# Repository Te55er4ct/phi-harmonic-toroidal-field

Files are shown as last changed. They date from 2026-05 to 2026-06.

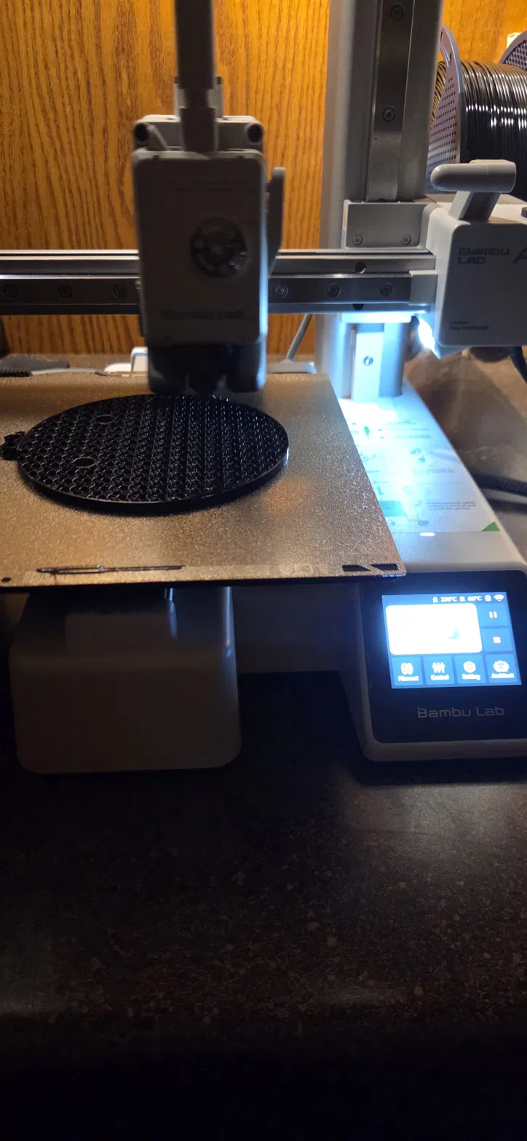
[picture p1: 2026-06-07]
sessions/2026-06-06_session1_v1/v1_first_print.png

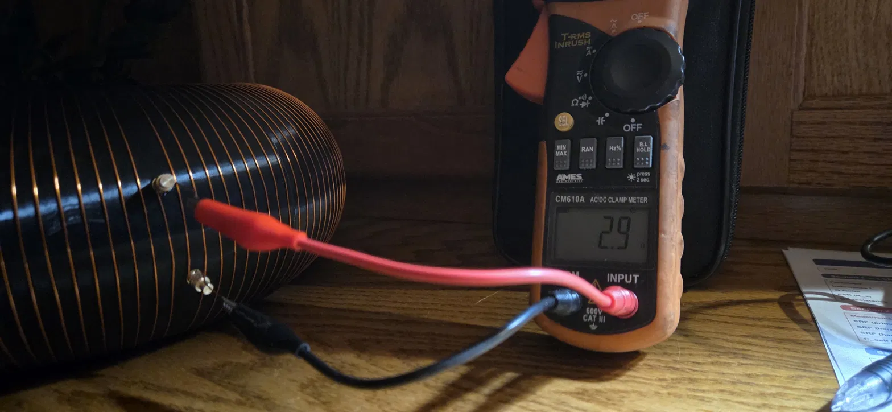
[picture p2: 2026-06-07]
sessions/2026-06-06_session1_v1/ohm_reading.png

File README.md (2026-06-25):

# Phi-Scaled Resonant Toroidal Research Platform
### *The Wierzbicki Phenomenon Omnivortex Device*
**Experimental Research · Ryan R. Wierzbicki · USA · 2026**

---

## Overview

This repository documents the design, fabrication, and experimental evaluation of a phi-proportioned toroidal field platform employing non-periodic winding geometry, Fibonacci-derived dimensional relationships, and multi-coil harmonic coupling at golden-angle offsets.

The platform investigates whether recursively phi-scaled toroidal structures and quasi-periodic winding distributions exhibit measurable differences in electromagnetic field organisation, resonance behaviour, harmonic distribution, and field coherence — compared to conventional toroidal architectures.

This project extends one specific, narrow, published result: Purnell et al.
(2018, *Physiological Reports*) reported that a phi-proportioned toroidal
electromagnetic array shifted human red blood cell morphology toward
golden-ratio proportions in a small (n=20), single-device, non-replicated
pilot study. That study used DC excitation through a conductive saline bath
and had no non-phi control geometry, so it cannot distinguish whether phi
geometry specifically — versus toroidal topology generally, the DC field, or
the saline coupling — is the active variable. This platform's three-version
comparative design (V1/V2/V3) exists to isolate that variable using an AC,
air-core implementation. See `docs/literature_review.md` for the full
evidentiary basis and explicit scope limits.

Cymatics (Jenny, 1967–74) motivates the node-frequency predictions tested in
Phase 2 — this is a citable, real body of acoustic-physics work, not a
biological claim. No claims of overunity performance, violation of
established physical law, or therapeutic/disease-treatment efficacy are
made. The purpose of this platform is experimental investigation of
measurable electromagnetic phenomena — inductance, Q, resonant frequency,
field distribution — produced by phi-harmonic geometry.

---

## Research Objectives

The platform is designed to investigate the following specific questions:

1. Do phi-proportioned toroidal geometries (R/r = φ) produce measurably different field distributions compared to non-phi toroidal geometries with identical winding configurations?

2. Do quasi-periodic winding offsets at the golden angle (137.5°) produce measurably different standing-wave node distributions compared to evenly periodic winding arrangements?

3. Do three mutually coupled windings in phi-harmonic phase relationships produce emergent field phenomena not predicted by analysis of each winding in isolation?

4. Does the combination of opposing primary and counter windings produce any measurable difference in Faraday-cage transmission compared to a single-winding control? (Framed as an electrical engineering question; see `docs/literature_review.md` §III for why this is not framed in terms of scalar-wave theory.)

5. Are Fibonacci node positions — predicted by the phi-spiral winding geometry — measurably associated with field concentration or standing-wave formation?

6. Do phi-harmonic driving frequencies (f(n) = 111 × φ^(n/3) Hz) produce resonant behaviour distinct from non-harmonic driving frequencies in this geometry?

---

## Theoretical Foundation

### The Motivating Result

Purnell et al. (2018, *Physiological Reports*) reported that a
phi-proportioned toroidal electromagnetic array shifted human red blood
cell morphology toward golden-ratio proportions in a small (n=20),
single-device, non-replicated pilot study using DC excitation through a
saline bath. The study had no non-phi control geometry, so it cannot
isolate whether phi geometry, toroidal topology generally, the DC field,
or the saline coupling produced the effect. This platform's V1/V2/V3
comparative design exists to isolate that variable with an AC, air-core
implementation. Full evidentiary basis and scope limits: `docs/literature_review.md`.

### Faraday-Cage Transmission Test

The V3 winding architecture (opposing primary/counter windings, 120° phase
offset) will be compared against V1/V2 single-winding controls for any
measurable difference in transmission through a grounded Faraday enclosure.
This is framed as an electrical engineering measurement, not as a test of
scalar-wave theory — see `docs/literature_review.md` §III for why that
framework is explicitly not part of this project's evidentiary basis. Any
unexpected result will be investigated via conventional EM coupling
mechanisms first.

### Cymatic Field Organisation

Jenny (1967–1974) demonstrated that specific driving frequencies produce reproducible geometric standing-wave patterns in physical media. The phi-harmonic node frequency series (111 × φ^(n/3) Hz) is predicted to produce distinct cymatic patterns corresponding to Fibonacci symmetry orders (3-fold, 5-fold, 8-fold, 13-fold) at successive node positions around the torus equator. This prediction is directly testable.

### Phi Geometry as Organisational Principle

The golden ratio φ = (1+√5)/2 = 1.6180... appears as a growth ratio throughout biological systems — phyllotaxis, vascular branching, neural architecture — because it maximises spatial coverage without self-overlap. The hypothesis under investigation is that a toroidal field structure proportioned to φ is geometrically congruent with biological field structures in a way that conventional integer-ratio geometries are not.

---

## Experimental Design

### Three-Version Comparative Framework

| Version | Label | Geometry | Winding | Variable Under Test |
|---|---|---|---|---|
| V1 | Control | Standard (R=80mm, r=45mm) | Poloidal standard | Baseline |
| V2 | Phi-Shell | Phi-proportioned (R=89mm, r=55mm) | Poloidal standard | Phi geometry alone |
| V3 | Omnivortex | Phi-proportioned (R=89mm, r=55mm) | Three phi-spiral windings | Phi geometry + phi winding |

This design enables isolation of the geometric effect (V1 vs V2), the winding effect (V2 vs V3), and the combined effect (V1 vs V3).

### Device Specifications

| Parameter | V1 Control | V2 Phi-Shell | V3 Omnivortex |
|---|---|---|---|
| Major Radius R | 80 mm | 89 mm (F11) | 89 mm (F11) |
| Minor Radius r | 45 mm | 55 mm (F10) | 55 mm (F10) |
| R / r | 1.778 | 1.618 (φ) | 1.618 (φ) |
| Outer Diameter | 250 mm | 288 mm | 288 mm |
| Winding type | Poloidal | Poloidal | Phi-spiral |
| Winding count | 1 | 1 | 3 |
| Turn count | 50 | 50 | 5 per winding |

---

## V3 Omnivortex Winding Architecture

| Winding | Colour | Gauge | Direction | Phase Offset |
|---|---|---|---|---|
| Primary | Red enamel | 18 AWG | Clockwise | 0° |
| Counter | Blue enamel | 18 AWG | Counter-clockwise | 120° |
| Harmonic | Green enamel | 20 AWG | Phi-rate advance | 137.5° (golden angle) |

Each winding closes at its own node contact — creating three closed toroidal inductors within the same phi-proportioned geometry. The harmonic winding advances at the golden angle per major turn (minor turns = major turns × φ = 8.09).

---

## Fibonacci Node Geometry

| Node | Angle | Predicted Frequency | Predicted Cymatic Form |
|---|---|---|---|
| 1 | 0.0° | 111.00 Hz | 3-fold symmetry |
| 2 | 137.5° | 130.31 Hz | 5-fold symmetry |
| 3 | 275.0° | 152.98 Hz | 6-fold symmetry |
| 4 | 52.5° | 179.60 Hz | 5-fold + ring |
| 5 | 190.0° | 210.85 Hz | 8-fold symmetry |
| 6 | 327.5° | 247.53 Hz | 8-fold + ring |
| 7 | 105.0° | 290.60 Hz | 13-fold symmetry |
| 8 | 242.6° | 341.16 Hz | Complex composite |

Node frequency series: **f(n) = 111 × φ^(n/3) Hz**

---

## Mathematical Framework

**Toroidal parametric surface:**

    P(t) = ( (R + r·cos(φ·t))·cos(t),  (R + r·cos(φ·t))·sin(t),  r·sin(φ·t) )

**Node frequency series:**

    f(n) = 111 × φ^(n/3)  Hz,   n = 0, 1, 2, ... 7

**Golden angle:**

    GA = 360 / φ² = 137.5077...°

**Standing-wave membrane model:**

    u(r, θ, t) = sin(m·π·r/R) · cos(n·θ) · cos(ω·t)

**Fibonacci dimensional relationships:**

    R = 89 mm = F(11),   r = 55 mm = F(10),   R/r = 1.6182 ≈ φ

---

## Measurement Protocol

### Phase 1 — Electromagnetic Characterisation
Instruments: LCR meter, oscilloscope, function generator, NanoVNA

- Inductance and Q factor comparison across V1, V2, V3
- Resonance frequency mapping and harmonic spectrum analysis
- Impedance sweep 1 Hz – 10 MHz
- Phase relationships between V3 windings

### Phase 2 — Field Distribution Mapping
Instruments: Gaussmeter, Arduino sweep driver

- Near-field magnetic flux mapping at predicted node positions
- Standing-wave node detection using particle medium
- Cymatic pattern documentation at each node frequency

### Phase 3 — Faraday-Cage Transmission Test
Instruments: Paired coil sets, oscilloscope, Faraday cage

- Faraday cage transmission test: V1 vs V2 vs V3
- Phase velocity measurement
- Any anomalous result investigated via conventional EM coupling mechanisms
  before any other interpretation

### Phase 4 — Biological Response Investigation

*Phase 4 investigations will be conducted within applicable regulatory
frameworks (IRB-equivalent oversight required for any biological subject)
and will not involve therapeutic claims. This phase is a long-horizon,
not-yet-scoped extension and is not a current commitment.*

- Replication attempt of Purnell (2018) RBC morphology measurement,
  parametrized across V1/V2/V3 to test whether phi geometry specifically
  is the active variable

---

## Driver Circuit

| Parameter | Value |
|---|---|
| Driver | 2 × L298N H-bridge + Arduino Nano |
| Supply voltage | 12V DC regulated |
| Series resistance | 1.5Ω 10W per winding |
| Peak current | ~7A per winding |
| Frequency range | 1 Hz – 100 kHz |
| Drive modes | In-phase / Anti-phase / Phase-offset / Sequential |

---

## Fabrication

All structural components are 3D-printed in PETG from parametrically generated STL files produced by `TorusGenerator.java` — a pure-Java parametric STL generator operating directly from mathematical definitions.

| Parameter | Value |
|---|---|
| Material | PETG |
| Segments | 8 per torus (45° arc each) |
| Layer height | 0.20 mm |
| Infill | Honeycomb 30% |
| Wall perimeters | 4 |
| Supports | None required |

---

## Historical Precedents

| Researcher | Year | Contribution |
|---|---|---|
| Nikola Tesla | 1898 | High-frequency electromagnetic therapeutic effects |
| Georges Lakhovsky | 1925 | Cellular LC oscillation theory; MWO clinical trials |
| Hans Jenny | 1967–74 | Cymatic standing-wave geometry at discrete frequencies |
| Herbert Fröhlich | 1968 | Quantum coherence in biological systems |
| Konstantin Meyl | 2001 | Scalar longitudinal wave theory and experimental replication |
| Thomas Valone | 2003 | Bioelectromagnetic healing: historical record and biophysical rationale |

---

## Current Status

| Date | Milestone |
|---|---|
| May 2026 | Theoretical framework complete |
| May 2026 | Parametric geometry and Java STL generator complete |
| May 2026 | Driver circuit specification complete |
| May 2026 | Repository established — public priority record |
| May 2026 | Documentation complete. Awaiting first print. |
| May 23, 2026 | First segment printed — V1 control |
| May 23, 2026 | OpenSCAD geometry validated — slits, pegs, sockets |
| May 23, 2026 | Bambu Lab A1 Mini operational |
| May 24, 2026 | Toroidal segment peg/socket alignment validated procedurally |
| May 24, 2026 | 45° segmented toroid architecture finalized for V1 testing 
| June 6, 2026 | **Phase 1 attempted — V1 only.** Measured L=0.47 mH, Q~161 @500kHz (dropping to ~14 near SRF), SRF≈1.000 MHz, C_self≈54 pF, DC resistance 2.9Ω, anti-resonance at 12.005 MHz. Wheeler-formula comparison corrected (predicted 0.323 mH; measured is ~45% higher, likely turn-to-turn proximity/mutual coupling not captured by the idealized formula). V2/V3 not yet built — Phase 1's full V1/V2/V3 comparison is not yet possible. |
| TBD | Phase 1 completion — V2/V3 build and measurement |
| TBD | Phase 2 field distribution mapping |
| TBD | Phase 3 Faraday-cage transmission test |
| TBD | Phase 4 biological response investigation |

---

## Research Position

This project investigates unconventional resonant geometries and winding architectures within experimental electromagnetic research. All measurements will employ appropriate instruments, documented procedures, and comparative baselines.

**This project does not claim:**
- Perpetual motion or overunity performance
- Violation of conservation of energy or Maxwell's equations
- Confirmed anomalous physics prior to experimental verification
- Therapeutic efficacy in the absence of controlled experimental data

**This project does claim:**
- Original parametric design of a phi-proportioned three-winding toroidal field platform
- Rigorous three-version experimental design for variable isolation
- Public priority record established May 2026
- Open research for collaborative independent verification

---

## License

Open research publication for collaborative experimentation and independent verification.  
All original theory, design, and documentation © R. Wierzbicki, 2026.  
Attribution required for derivative work and published results.

---

*"The convergence of φ, the Fibonacci sequence, toroidal geometry, Tesla's 3·6·9,  
and a century of bioelectromagnetic research is not accidental.  
They are different descriptions of the same underlying structure —  
the way energy organises itself when given the freedom to do so."*

— R. Wierzbicki, 2026

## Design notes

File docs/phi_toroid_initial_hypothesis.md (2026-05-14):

# Quasi-Periodic Toroidal Resonance Structures
## Initial Engineering Hypothesis & Research Framework

---

# Abstract

This project investigates whether quasi-periodic toroidal winding geometries exhibit measurable electromagnetic behaviors distinct from conventional periodic toroidal winding architectures.

The research focuses specifically on:

- distributed parasitic capacitance,
- resonance bandwidth characteristics,
- harmonic distribution,
- inductive coupling behavior,
- field topology,
- and electromagnetic interference behavior.

The central experimental concept is a toroidal multi-winding structure utilizing irrational angular traversal relationships derived from golden-angle distributions and Fibonacci-scaled winding ratios.

Unlike conventional evenly periodic toroidal windings, the proposed architecture intentionally prevents exact spatial repetition of winding overlap across the toroidal surface.

The project does not begin with assumptions regarding:

- overunity,
- vacuum energy extraction,
- anomalous power generation,
- or nonphysical energy systems.

Instead, the project investigates whether non-periodic resonant geometries may produce useful and measurable electromagnetic behaviors comparable to other known aperiodic systems in:

- metamaterials,
- quasi-crystal structures,
- topological photonics,
- fractal antennas,
- and magnetic confinement topology.

---

# 1. Research Motivation

Modern electromagnetic systems are increasingly limited by:

- parasitic capacitance,
- harmonic congestion,
- EMI leakage,
- resonance instability,
- distributed coupling artifacts,
- and high-frequency interference.

Conventional toroidal windings are typically periodic structures with uniformly repeating turn spacing.

This creates predictable distributed capacitive networks and repeated field overlap regions.

The present research explores whether quasi-periodic winding distributions may:

- distribute harmonic interactions more uniformly,
- reduce localized field concentration,
- broaden resonance response,
- suppress sharp parasitic resonant spikes,
- or alter coupling topology.

The project draws conceptual inspiration from:

- Nikola Tesla's emphasis on resonance and harmonic systems,
- Georges Lakhovsky's broadband oscillatory concepts,
- toroidal confinement geometry in stellarator research,
- quasi-periodic mathematical systems,
- and modern topological electromagnetic research.

However, all project development is grounded in experimentally measurable electromagnetic behavior.

---

# 2. Foundational Hypothesis

## Primary Hypothesis

Quasi-periodic toroidal winding distributions alter distributed parasitic capacitance and harmonic resonance behavior compared to conventional periodic toroidal winding architectures.

---

## Secondary Hypotheses

### H1 — Harmonic Distribution

Quasi-periodic winding traversal produces broader and less sharply localized harmonic resonance structures than periodic windings.

---

### H2 — Distributed Capacitance

Irrational angular winding distributions reduce repeated parallel overlap regions and therefore alter effective distributed capacitance.

---

### H3 — Resonance Bandwidth

Non-periodic winding structures broaden impedance response curves and reduce narrow self-resonant spikes.

---

### H4 — Coupling Topology

Counter-wound quasi-periodic structures produce measurable differences in inductive coupling behavior under dynamic load conditions.

---

### H5 — Field Distribution

Quasi-periodic toroidal geometries produce distinguishable near-field spatial distributions relative to periodic toroidal controls.

---

# 3. Mathematical Framework

## Golden Angle Distribution

The winding traversal uses the golden angle:

φ = (1 + √5) / 2 ≈ 1.6180339887

Golden Angle:

θg = 2π / φ² ≈ 137.507764°

The golden angle is significant because irrational angular progression prevents exact spatial repetition.

This creates quasi-periodic surface coverage similar to:

- phyllotaxis distributions,
- irrational rotational systems,
- low discrepancy sequences,
- and quasi-crystal packing structures.

---

## Toroidal Traversal

The winding path is parameterized over a toroidal manifold.

Poloidal progression:

θ(t) = ±2πNt

Toroidal progression:

φ(t) = Nθg t + φ₀

Where:

- N = winding turns,
- θg = golden angle,
- φ₀ = phase offset,
- t ∈ [0,1]

This creates a quasi-periodic winding lattice over the toroidal surface.

---

## Fibonacci Scaling

Fibonacci relationships are used as proportional design constraints rather than as claims of intrinsic physical significance.

Example winding relationships:

- Primary: 144 turns
- Counter: 89 turns
- Harmonic: 55 turns

These relationships maintain recursive scaling and irrational ratio relationships between winding systems.

---

# 4. Experimental Architecture

## Geometry

Toroidal geometry:

- Major radius: R
- Minor radius: r
- Ratio: R/r ≈ φ

The device uses:

- primary winding layer,
- counter-wound layer,
- harmonic winding layer,
- axial reference structure,
- and distributed tap-node regions.

---

## Winding Structure

### Primary Layer

- clockwise traversal
- quasi-periodic toroidal progression
- primary excitation winding

### Counter Layer

- counter-clockwise traversal
- offset phase relationship
- inductive interaction layer

### Harmonic Layer

- reduced turn count
- secondary coupling topology
- distributed harmonic interaction

---

## Materials

Initial prototypes are intended for:

- low-cost fabrication,
- rapid iteration,
- and comparative testing.

Initial materials:

- PETG or PLA toroidal forms,
- enamel copper magnet wire,
- optional ferrite inserts,
- non-ferromagnetic fasteners.

---

# 5. Experimental Methodology

## Control Structure

A conventional periodic toroidal winding shall be constructed as a control.

The control and experimental structures shall maintain:

- identical dimensions,
- identical wire gauge,
- identical turn count,
- identical core material,
- and identical testing conditions.

Only winding topology shall differ.

---

## Measured Parameters

Initial measurements include:

### Electrical

- inductance,
- impedance,
- self-resonant frequency,
- Q factor,
- distributed capacitance,
- harmonic spectra,
- coupling efficiency,
- and thermal behavior.

### Field Measurements

- near-field magnetic mapping,
- EMI leakage,
- resonance spatial distribution,
- and coupling topology.

### Instrumentation

Potential instrumentation includes:

- oscilloscope,
- vector network analyzer,
- SDR spectral analysis,
- impedance analyzer,
- current probes,
- and field probes.

---

# 6. Related Scientific Domains

The project intersects conceptually with several established research territories.

---

## 6.1 Stellarator and Magnetic Confinement Topology

Fusion confinement systems such as stellarators utilize nontrivial toroidal magnetic geometries to maintain stable field structures.

In such systems:

- irrational rotational transforms,
- non-periodic field topology,
- and ergodic field traversal

strongly influence confinement behavior.

The present project does not claim equivalence with plasma confinement systems.

However, these systems demonstrate that toroidal topology and quasi-periodic field organization can significantly affect field behavior.

---

## 6.2 Metamaterials and Topological Electromagnetics

Modern metamaterial and topological photonics research demonstrates that:

- geometry,
- boundary conditions,
- and non-periodic structures

can alter wave propagation behavior.

Relevant adjacent concepts include:

- toroidal dipoles,
- anapole modes,
- structured wavefronts,
- and topological field organization.

---

## 6.3 Aperiodic RF Structures

Nonuniform resonant structures are already used in:

- fractal antennas,
- log-periodic antennas,
- distributed RF structures,
- and broadband impedance systems.

These systems demonstrate that non-periodic geometry can measurably affect:

- resonance,
- bandwidth,
- and harmonic behavior.

---

# 7. Current Project Position

At the present stage, the project should be considered:

- exploratory,
- experimental,
- geometry-driven,
- and measurement-focused.

No claims are currently made regarding:

- excess energy generation,
- vacuum energy extraction,
- scalar energy,
- or violations of established electromagnetic theory.

The project instead seeks to determine whether quasi-periodic toroidal winding structures produce measurable and potentially useful electromagnetic characteristics.

---

# 8. Initial Research Roadmap

## Prototype 0 — Control Toroid

Conventional periodic winding.

Purpose:

- baseline resonance behavior,
- baseline parasitic response,
- baseline harmonic spectra.

---

## Prototype 1 — Golden-Angle Winding

Single quasi-periodic winding.

Purpose:

- compare resonance response,
- compare harmonic distribution,
- compare self-resonance.

---

## Prototype 2 — Counter-Wound Structure

Add secondary counter-wound layer.

Purpose:

- investigate coupling behavior,
- phase interaction,
- and harmonic redistribution.

---

## Prototype 3 — Multi-Layer Harmonic Structure

Introduce harmonic scaling layer.

Purpose:

- broadband response analysis,
- distributed coupling studies,
- and modal interaction analysis.

---

# 9. Conclusion

The project has evolved from conceptual resonance exploration into a structured investigation of quasi-periodic electromagnetic geometry.

The central premise is not that geometry creates energy.

Rather:

The project investigates whether non-periodic toroidal winding architectures organize electromagnetic interactions differently than conventional periodic structures.

This question is:

- measurable,
- experimentally approachable,
- and grounded in adjacent domains of modern electromagnetic research.

The immediate objective is therefore:

To build repeatable, instrumented prototypes capable of generating comparative data between periodic and quasi-periodic toroidal winding systems.

Only measured and repeatable behavior will determine future theoretical development.

---

The project has evolved from conceptual resonance exploration into a structured investigation of quasi-periodic electromagnetic geometry.

The central premise is not that geometry creates energy.

Rather:

The project investigates whether non-periodic toroidal winding architectures organize electromagnetic interactions differently than conventional periodic structures.

This question is:

- measurable,
- experimentally approachable,
- and grounded in adjacent domains of modern electromagnetic research.

The immediate objective is therefore:

To build repeatable, instrumented prototypes capable of generating comparative data between periodic and quasi-periodic toroidal winding systems.

Only measured and repeatable behavior will determine future theoretical development.

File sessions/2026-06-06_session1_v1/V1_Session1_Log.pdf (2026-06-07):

## Omnivortex V1 — Phase 1 Session 1 Measurement Log

R=89mm r=55mm · 123T · 22 AWG · github.com/Te55er4ct/phi-harmonic-toroidal-field

Date: | 06/06/2026 | Time: 15:03-16:44 CDT | Temp: 84°F outdoor | Humidity: | 38% | Location: | Outdoors / wooden sawhorse
Section 1 — LCR Meter (Proster BM4070) | Fixed freq ~1kHz
Parameter | ~1kHz | 10kHz | 100kHz | Units | Notes
Inductance L | 0.47 | — | — | mH | Confirmed indoors & outdoors
Q factor | ~1.0 | — | — | — | Calc: wL/R; NanoVNA: 161@500k, 14@SRF
ESR (R_s) | — | — | — | ohm | Not displayed on BM4070
DC resistance | 2.9 | — | — | ohm | Ames CM610A clamp meter
Section 2 — NanoVNA-H Self-Resonant Frequency | fw v1.2.44 / Saver 0.7.3
Measurement | Value | Units | Notes
SRF primary peak | ~1.000 | MHz | Phase zero crossing 1.000-1.00040 MHz
SRF harmonic 2 | — | MHz | Not yet measured
SRF harmonic 3 | — | MHz | Not yet measured
C_self calculated | ~54 | pF | C=1/(4pi^2 x f^2 x L)

### Section 3 — Impedance Sweep Key Points (500kHz - 30MHz)

Feature | Freq (MHz) | |Z| (ohm) | Phase (deg) | Notes
Inductive region low end | 0.500 | ~1880 | +3.04 | Series L ~600uH, Q=161
SRF primary | ~1.000 | ~10500 | ~0 | Phase zero crossing confirmed
Q at SRF | ~1.000 | ~10500 | ~0 | Q = ~14 near SRF
Capacitive region start | >1.001 | — | neg | Series L goes negative
VSWR minimum (wide) | 12.005 | 141 | -20.53 | Min VSWR 6.452
Anti-resonance | 12.005 | 141 | -20.53 | Series L = -2.06uH
Upper limit | 30.000 | — | — | No further features this session

### Section 4 — Instrument & File Log

Cal file: | | V1_500k_30M (OSL via calibration assistant)
.s1p file: | | V1_SRF_1M.s1p
Screenshots: | nanovna_2026-06-06_16-12-32 thru 16-44-31 (8 captures)
NanoVNA fw: | NanoVNA-H v1.2.44
Instruments: | Proster BM4070 LCR | Ames CM610A clamp | NanoVNA-H

Observations / anomalies / notes
L=0.47mH confirmed identical indoors and outdoors — no EMI effect from indoor environment on LCR reading. SRF ~1.000MHz by phase zero crossing. Capacitive above, inductive below. C_self ~54pF calculated. NanoVNA SOL cal failed at 100k and 500k start frequencies. Resolved via calibration assistant at 500k. Connection: bare coil wire wrapped on SMA connector. SMA-to-alligator pigtails needed for Session 2.
DC resistance 2.9 ohm (spec 3.0 ohm). WiFi active on laptop — no artifacts visible in sweep range.
Operator: | Wierzbicki | Session #: | 1 | Git commit hash: | (fill after push)
Wierzbicki Phenomenon Omnivortex Device | V1 Phase 1 Session 1 | 06 June 2026 | github.com/Te55er4ct/phi-harmonic-toroidal-field

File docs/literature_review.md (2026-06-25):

# Literature Review & Research Precedents
## Phi-Harmonic Toroidal Field Research

---

## Introduction

This project tests a narrow, falsifiable engineering question: does
phi-proportioned toroidal coil geometry and golden-angle (137.5°) winding
distribution produce measurably different electrical and field
characteristics compared to a conventional toroid wound with the same wire
gauge, turn count, and core dimensions?

This document surveys the published work directly relevant to that question.
It deliberately excludes sources whose claims are not accepted by mainstream
physics or medicine, even where those sources historically inspired interest
in resonance-based or toroidal devices. Citing discredited or non-replicated
work as supporting evidence would misrepresent the actual evidentiary basis
for this project and invites — correctly — the "quack device" framing this
project should avoid. The honest position is: this is original instrumentation
work motivated by one narrow, real, non-replicated prior result, not a
synthesis of an established field.

---

## I. THE PRIOR RESULT THIS PROJECT EXTENDS

### Purnell, M.C., Butawan, M.B.A., Ramsey, R.D. — "Bio-field array: a
dielectrophoretic electromagnetic toroidal excitation to restore and
maintain the golden ratio in human erythrocytes" (2018)
*Physiological Reports, Vol. 6, Issue 12*
*US Patent 2017/0232253; PCT/US18/26932*

**What it is:** An IRB-approved human pilot study (n=20) using a toroidal
electromagnetic array with phi-proportioned geometry, DC-excited (2.5–3A)
through conductive rings in a hypotonic saline foot bath. Measured red
blood cell morphology and select serum chemistry before/after six
35-minute sessions over two weeks.

**Reported results:** RBC morphology shifted toward golden-ratio
proportions following treatment; reduced rouleaux (RBC stacking)
formation; decreased serum CO2 (p=0.017).

**What this does and does not establish:**
- It is the only published human trial of a phi-proportioned toroidal EM
  device that this review identified. It is real, peer-reviewed (note:
  *Physiological Reports* is a legitimate but lower-impact open-access
  journal, not a flagship physiology venue), and reports a specific,
  checkable result.
- It does **not** establish that phi geometry specifically is the active
  variable — the study used a single device with no non-phi control
  geometry. The morphological effect could be attributable to the DC
  field, the saline coupling, the toroidal topology generally, or the phi
  proportioning specifically; the design cannot distinguish between these.
- It does not generalize to AC excitation, air-core devices, or any
  outcome beyond RBC morphology and the one serum marker reported.
- As of this writing, no independent replication of this device or result
  has been published. Citation count is low and consists mostly of papers
  citing the golden-ratio-RBC theoretical background, not replications.

**This project's relationship to it:** This is a parametric extension, not
a validation. Purnell's result is the single concrete data point motivating
the question "does phi-proportioned toroidal geometry matter electromagnetically,"
applied here to a structurally different implementation (AC pulsed, air-core,
no biological subject) specifically to isolate the geometric variable Purnell's
single-device design could not isolate.

---

## II. BACKGROUND PHYSICS — TOROIDAL FIELD CONFIGURATIONS

### FLEET Project (Flying Electromagnetic Toroids) — University of
Southampton, ERC Advanced Grant

Studies the generation and propagation of toroidal electromagnetic pulses
at optical frequencies. Relevance to this project is narrow: it confirms
that toroidal (donut-topology) field configurations are legitimate,
non-trivial solutions to Maxwell's equations, studied by mainstream
academic physics with major institutional funding. It says nothing about
biological effects, golden-ratio geometry, or Hz/kHz-frequency behavior —
those are separate, untested extrapolations this project does not claim
FLEET supports.

### Zhang & Ou-Yang — golden ratio in erythrocyte morphology (2016, arXiv preprint)

A theoretical analysis proposing that healthy resting RBC geometry
approximates golden-ratio proportions. Provides the geometric premise
underlying Purnell's measurement choice (why measure RBC morphology
specifically). Note: arXiv preprints are not peer-reviewed; this is cited
as background context for why Purnell chose that outcome measure, not as
independently validated fact.

---

## III. WHAT THIS PROJECT DOES NOT CLAIM

To be explicit about scope, this project does not claim or rely on:

- Cellular-resonance disease theories (e.g., Lakhovsky's multi-wave
  oscillator and associated cancer claims). These were never
  independently replicated and are not accepted by mainstream oncology
  or biophysics. They are not part of this project's evidentiary basis.
- Orgone or bioelectric "energy" theories (e.g., Reich). The FDA obtained
  a federal injunction against related devices in the 1950s for false
  medical claims. Not part of this project's evidentiary basis.
- "Scalar wave" physics claiming superluminal propagation or Faraday-cage
  penetration (e.g., Meyl). Not accepted by mainstream physics; published
  outside mainstream physics venues. If Phase 3 testing (Faraday-cage
  transmission comparison across winding configurations) shows any
  unexpected transmission difference, that result will be reported and
  investigated as an anomaly to be explained by conventional means first
  — not interpreted as confirmation of scalar-wave theory.
- Any disease-treatment, cancer-treatment, or other health claim. This
  project's measurements are electrical and field-distribution
  characteristics (inductance, Q, SRF, field strength/geometry). It is
  not a medical device and makes no therapeutic claims.

---

## IV. OPEN QUESTIONS THIS PROJECT IS DESIGNED TO ADDRESS

1. **Does phi-proportioned toroidal geometry produce measurably different
   field distributions than a conventional toroid of identical wire,
   turns, and core dimensions?** Addressed by V1 (control) vs V2
   (phi-shell) comparison.
2. **Does golden-angle (137.5°) winding distribution produce measurably
   different standing-wave or field patterns than periodic winding, holding
   geometry constant?** Addressed by V2 vs V3 comparison.
3. **Do opposing-direction windings at 120° phase offset produce any
   measurable difference in Faraday-cage transmission compared to a
   single-winding control?** Addressed by Phase 3. This is an electrical
   engineering question (does the field couple through a grounded
   enclosure differently), framed without reference to scalar-wave theory.
4. **Can the Purnell (2018) RBC morphology result be replicated using an
   open-source implementation, and does it depend on phi geometry
   specifically (testable via the V1/V2/V3 control)?** A long-horizon
   question; any work here would need a proper IRB-equivalent protocol and
   is out of scope for current hardware-characterization phases.

None of these questions require, or benefit from, invoking cellular
resonance theory, orgone theory, or scalar wave physics to ask or answer.

---

## V. ADDENDUM — Phi-Reduction of Astronomical Periods vs. Node Series

*(Carried forward unchanged from the prior review — this section already
meets the evidentiary standard the rest of this document now follows.)*

### Background

Hans Cousto's "Cosmic Octave" method reduces a natural period to an
audible frequency by repeated octave doubling/halving. The node series
used in this project's frequency design, f(n) = 111 × φ^(n/3), uses phi
scaling instead of octave scaling. This section tests whether natural
astronomical periods, phi-reduced instead of octave-reduced, land near
frequencies already present in the node series — a series derived with no
reference to astronomy.

### Results

| Source | Octave-reduced (Hz) | Phi-reduced (Hz) | Nearest node | Δ |
|---|---|---|---|---|
| Earth sidereal day | 194.71 | 148.00 | node[2] = 152.98 | −3.26% |
| Earth solar day | 194.18 | 147.59 | node[2] = 152.98 | −3.52% |
| Earth orbital year | 136.10 | 130.11 | node[1] = 130.31 | −0.15% |
| Lunar sidereal month | 113.72 | 156.85 | node[2] = 152.98 | +2.52% |
| Lunar synodic month | 105.21 | 211.30* | node[4] = 210.85 | +0.20% |
| Schumann resonance | 125.28 | 140.50 | node[1] = 130.31 | +7.82% |

*Reduced by one additional φ-octave for direct comparison.

### Interpretation

2 of 6 independently phi-reduced periods land within 0.2% of pre-existing
node frequencies; the remaining 4 miss by 2.5–8%. This is reported as a
2-out-of-6 correspondence, not a uniform pattern. With 8 node frequencies
and 6 candidate periods, some near-coincidence is statistically expected by
chance; a rigorous treatment requires testing hit rates against a null
distribution of random period sets before treating this as more than a
suggestive observation. **No causal or physically meaningful relationship
between astronomical periods and node frequencies is claimed.**

### Sources

Fiorenza, N.A. *Planetary Parameter Comparisons*. Rev. 2.0.0, 1987.
Cousto, H. *The Cosmic Octave: Origin of Harmony*. LifeRhythm, 1988.

---

## VI. COMPLETE SOURCE LIST

| Author | Title | Year | Venue | Status |
|---|---|---|---|---|
| Purnell, Butawan, Ramsey | Bio-field array... | 2018 | *Physiological Reports* 6(12) | Peer-reviewed, n=20, not independently replicated |
| Zhang & Ou-Yang | Golden ratio in erythrocyte morphology | 2016 | arXiv preprint | Not peer-reviewed; theoretical background only |
| FLEET Project, U. Southampton | Flying Electromagnetic Toroids | 2023+ | ERC-funded research program | Mainstream physics; unrelated to bio-effects |
| Fiorenza, N.A. | Planetary Parameter Comparisons | 1987 | Self-published reference tables | Source data for Section V only |
| Cousto, H. | The Cosmic Octave | 1988 | LifeRhythm | Source data for Section V only |

---

*Literature review — revised 2026-06-25 to remove non-replicated and
discredited sources (Lakhovsky, Reich, Meyl, Hollwich, Sloan) that were
present in the prior draft. Scope narrowed to sources that are either
peer-reviewed with stated limitations, or explicitly marked as background/
theoretical context. No disease-treatment or health claims are made by
this project.*

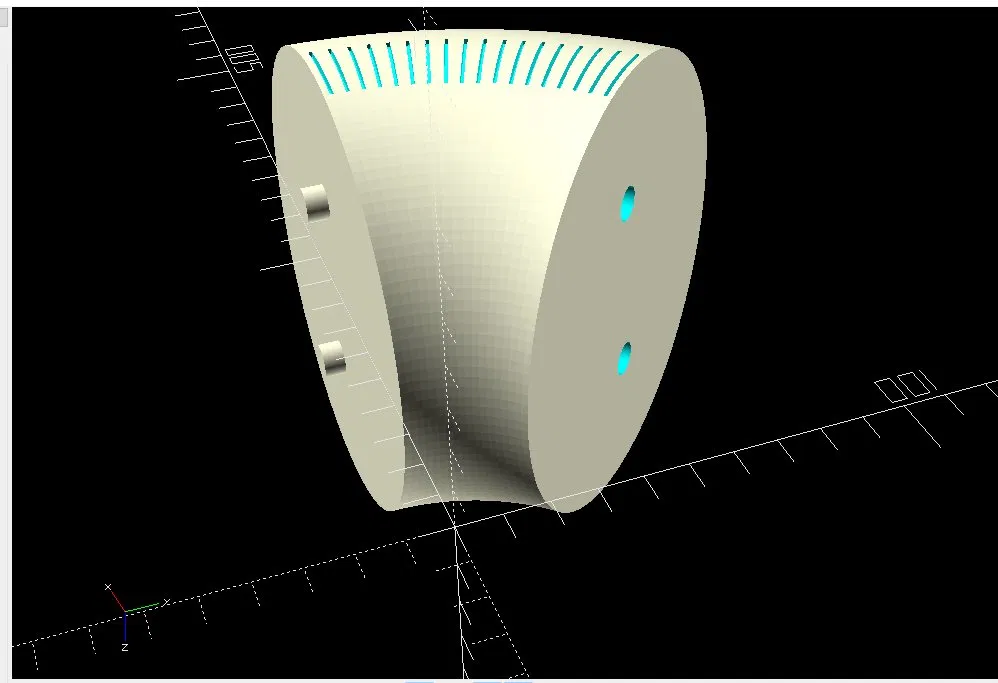
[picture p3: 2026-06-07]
sessions/2026-06-06_session1_v1/v1_openSCAD_design.png

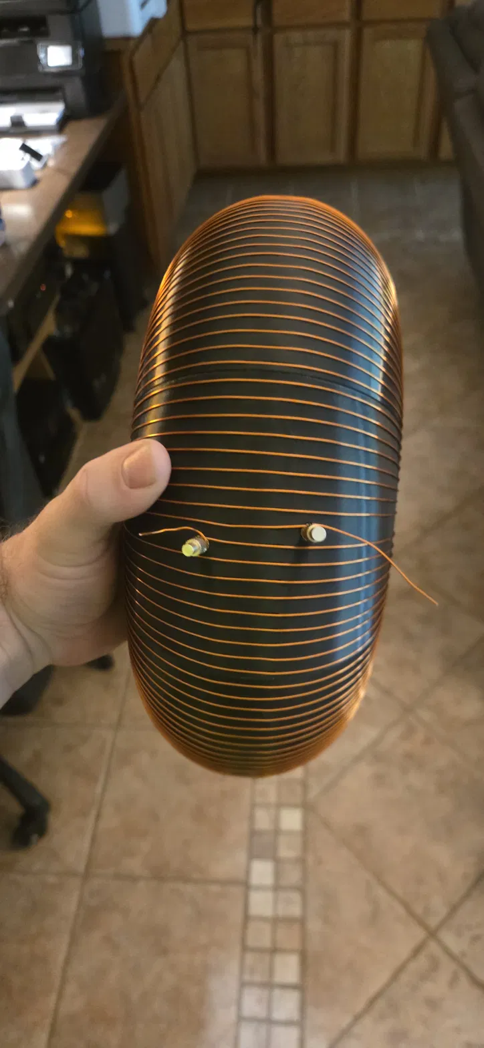
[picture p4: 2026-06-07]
sessions/2026-06-06_session1_v1/v1_winding_terminals.png

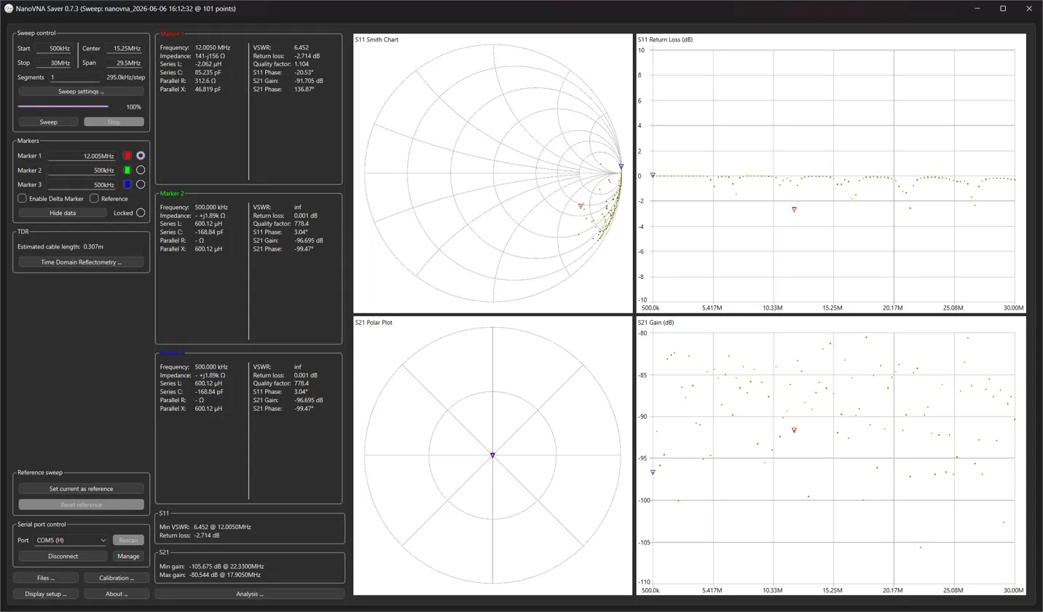
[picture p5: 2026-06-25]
sessions/2026-06-06_session1_v1/vna_sweep_500k-30M.webp

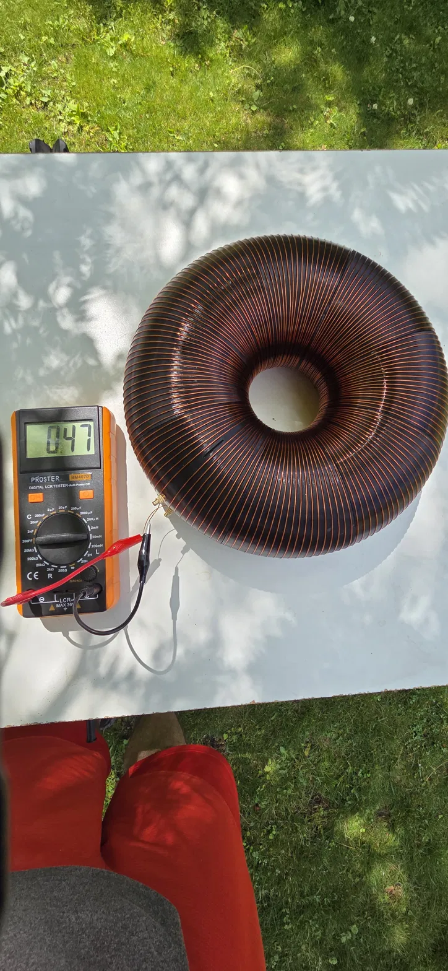
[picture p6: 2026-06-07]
sessions/2026-06-06_session1_v1/Inductance_reading.png

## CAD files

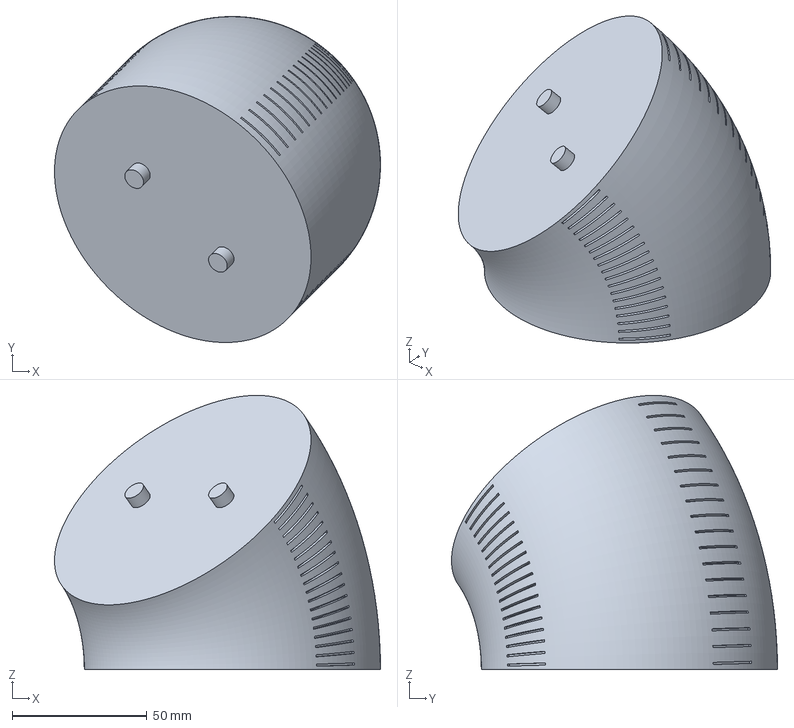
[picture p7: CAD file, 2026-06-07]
models/master_blank_torus_V1_baseline_section3.1.3mf
121.1 x 121.1 x 101.8 mm

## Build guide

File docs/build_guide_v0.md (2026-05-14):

# Build Guide — Prototype V0
## Control Toroid (Conventional Periodic Winding)

**Status:** First build  
**Purpose:** Establish baseline measurements for comparison against quasi-periodic prototypes  
**Difficulty:** Beginner  
**Estimated build time:** 3–4 hours

---

## Why Build the Control First

Every experimental result is only meaningful relative to a baseline.
Prototype V0 is that baseline.

It uses identical dimensions and materials to V1 and V2, with one difference:
conventional evenly-spaced winding. Building and measuring V0 first means
any differences observed in V1 and V2 are attributable to winding topology —
not to unknown variables in materials, dimensions, or technique.

**Do not skip the control build.**

---

## Bill of Materials

| Item | Quantity | Specification | Approx. Cost | Source |
|---|---|---|---|---|
| Toroid former V0 (printed) | 1 | PLA or PETG, R=89mm, r=55mm | ~$3–8 | Print from `cad/toroid_former_v0.stl` |
| Enameled copper wire | ~20m | 24 AWG (0.51mm) | ~$8 | Amazon, electronics suppliers |
| Nylon M8 bolt + nut | 1 set | Non-ferromagnetic | ~$1 | Hardware store |
| BNC or SMA connector | 1 | Panel mount or PCB type | ~$3 | Amazon, Mouser |
| Solder + flux | — | Electronics grade | — | On hand |
| Heat-shrink tubing | 4 pieces | 3mm diameter | ~$1 | On hand |
| Cyanoacrylate (super glue) | small amount | Thin viscosity | — | On hand |
| Small piece of cardboard | 1 | Wire management during winding | — | On hand |

**Total estimated material cost: ~$15–25**

---

## Tools Required

| Tool | Notes |
|---|---|
| 3D printer | For former — or send to print service |
| Soldering iron | 350°C tip, fine point preferred |
| Wire strippers | Set for 24 AWG |
| Multimeter | Continuity + resistance |
| Calipers | Verify printed dimensions |
| Helping hands / vise | Hold former while winding |
| Permanent marker | Mark turn positions |
| Ruler or tape measure | Measure wire length |
| Scissors | |

---

## Step 1 — Print and Verify the Former

1. Print `cad/toroid_former_v0.stl` with these settings:

   | Setting | Value |
   |---|---|
   | Material | PLA or PETG |
   | Layer height | 0.15 mm |
   | Infill | 20% (structural only — not a load-bearing part) |
   | Walls | 3 perimeters |
   | Supports | None required |
   | Orientation | Flat face down |

2. After printing, verify dimensions with calipers:

   | Dimension | Target | Tolerance |
   |---|---|---|
   | Major radius R | 89 mm | ± 0.5 mm |
   | Minor radius r | 55 mm | ± 0.5 mm |
   | Outer diameter | 288 mm | ± 1 mm |
   | Inner hole diameter | 68 mm | ± 1 mm |

3. Check the surface is smooth and free of print artifacts that could
   damage wire insulation during winding. Sand lightly if needed.

---

## Step 2 — Calculate and Prepare Wire

For a conventional winding with N = 144 turns on this toroid:

```
Circumference of tube cross-section = 2π × r = 2π × 55 = 345 mm per turn
Total wire length = 144 turns × 345 mm = ~49.7 m
Add 20% for routing and leads = ~60 m total

Cut a working length of 65 m to be safe.
```

Before cutting:
1. Measure and cut 65 m of 24 AWG enameled wire
2. Wind it loosely into a shuttle or bobbin to feed through the toroid hole
3. Leave a 20 cm tail at the start for the lead wire

---

## Step 3 — Mark Turn Positions

For a conventional (control) winding, turns are evenly spaced:

```
Angular spacing = 360° / 144 = 2.5° between turns
```

1. Using a permanent marker, make a small mark at position 0°
   on the outer equator of the toroid
2. This is your starting point — all other positions are reference only
3. You do not need to mark all 144 positions — just maintain
   consistent visual spacing as you wind

---

## Step 4 — Wind the Primary Winding

This is the meditative part. Take your time. Consistency matters more than speed.

1. Mount the toroid on the nylon bolt — this lets you rotate it freely
   while keeping it stable

2. Thread the wire end through the center hole and begin winding:
   - Pass the wire through the hole (poloidal direction)
   - Bring it over the outside of the tube
   - Back through the hole again
   - That is one turn

3. Maintain even spacing between turns — roughly 2.5° apart visually

4. Every 10 turns, place a tiny dot of super glue on the wire
   to hold position while you continue. Use sparingly.

5. Wind all 144 turns in the **clockwise** direction
   (when viewed from above)

6. Leave a 20 cm tail at the finish

**If you lose count:** use a piece of tape to mark every 10th turn as you go.

---

## Step 5 — Terminate and Solder

1. Strip 15mm of enamel from each wire end:
   - Use fine sandpaper (400 grit) or a lighter flame
   - Verify with multimeter — continuity between the two ends
   - If no continuity: enamel not fully removed — strip again

2. Tin both wire ends with solder

3. Solder to BNC or SMA connector:
   - One wire to center pin
   - Other wire to ground/shell
   - Keep leads as short as possible

4. Cover solder joints with heat-shrink

---

## Step 6 — Initial Electrical Verification

Before any RF measurement, verify basic electrical integrity:

| Test | Method | Expected Result |
|---|---|---|
| Continuity | Multimeter across connector | < 5 Ω (wire resistance) |
| No shorts to former | Multimeter, wire to former surface | Open circuit (> 1 MΩ) |
| DC resistance | Multimeter, 4-wire if available | Record value |

**Record DC resistance:** ___ Ω

Theoretical DC resistance for 60m of 24 AWG:
```
Resistance = length × resistivity = 60m × 84.2 mΩ/m ≈ 5.1 Ω
```
Measured value should be within ± 1 Ω of this. Higher means a bad
connection. Lower is not possible — recheck your calculation.

---

## Step 7 — Photograph

Take four standardized photographs and add to `photos/prototype_v0/`:

- [ ] `top_view.jpg`
- [ ] `side_0deg.jpg`
- [ ] `side_90deg.jpg`
- [ ] `isometric.jpg`

These photos become part of the permanent record.

---

## Step 8 — First Measurements

With the prototype complete and verified, proceed to measurements
following the procedures in `docs/experimental_protocol.md`.

Record all results in a copy of `docs/measurement_log_template.md`
saved as `data/prototype_v0/YYYY-MM-DD_run01_v0_control.md`.

**Key measurements to establish baseline:**

1. Impedance sweep: 100 kHz – 30 MHz
2. Record: self-resonant frequency, Q factor, inductance at 100 kHz
3. Repeat 3 times to establish repeatability

---

## Troubleshooting

| Problem | Likely Cause | Solution |
|---|---|---|
| No continuity | Enamel not stripped | Re-strip both ends with sandpaper |
| Very high resistance | Cold solder joint | Reflow with fresh solder |
| Erratic VNA trace | Loose connection | Check all connections, recalibrate |
| SRF not visible in sweep | SRF outside range | Extend sweep to 100 MHz |
| Turns not staying in place | Insufficient glue | Add more CA glue at 10-turn intervals |

---

## What to Expect

For a 144-turn toroidal inductor with R=89mm, r=55mm, 24 AWG wire:

```
Approximate inductance:    3–6 μH  (measure to confirm)
Approximate SRF:           5–15 MHz (depends on winding tightness)
Approximate Q at SRF:      50–200   (air core, 24 AWG)
```

These are rough estimates only. The actual measurements are what matter.

---

## Next Step

Once V0 is measured and documented:
→ Proceed to [prototype_v1/build_guide.md](../prototype_v1/build_guide.md)

The quasi-periodic winding build uses the same process with one
critical difference: golden-angle turn spacing instead of even spacing.

---

*"The control structure exists and will be measured identically."*

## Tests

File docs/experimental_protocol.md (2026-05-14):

# Experimental Protocol
## Quasi-Periodic Toroidal Resonance Structures

**Version:** 1.0  
**Status:** Active  
**Last updated:** May 2026

---

## Purpose

This document defines standard measurement procedures for comparing
quasi-periodic toroidal winding geometries against conventional periodic
baselines. All measurements must be performed consistently across all
prototypes to enable valid comparison.

Deviations from this protocol must be noted in the measurement log.

---

## Equipment

### Minimum Configuration

| Instrument | Purpose | Example Models |
|---|---|---|
| Vector network analyzer (VNA) | Impedance sweep, S-parameters | NanoVNA-H4, LiteVNA 64 |
| LCR meter | Low-frequency L/C/R | DE-5000, VICTOR 4090C |
| Multimeter | DC resistance, continuity | Any ≥ 4.5 digit |
| Calibration kit | SOLT calibration | Matched to VNA connector type |
| Non-ferromagnetic mount | Fixture for toroid under test | Nylon bolt + 3D-printed stand |

### Extended Configuration (later phases)

| Instrument | Purpose |
|---|---|
| Oscilloscope ≥ 100 MHz | Time-domain waveform capture |
| Function generator | Controlled drive signal |
| Current probe | Non-invasive current measurement |
| IR sensor or thermal camera | Thermal loss comparison |
| Small pickup coil | Near-field spatial mapping |

---

## Calibration Procedure

Perform before every measurement session without exception.

1. Allow VNA to warm up for ≥ 10 minutes
2. Perform full SOLT calibration **at the measurement plane**
   — at the point where the device under test (DUT) connects,
   not at the far end of the cable
3. Verify calibration with known reference:
   - Open: |S11| ≈ 0 dB, phase ≈ 180°
   - Short: |S11| ≈ 0 dB, phase ≈ 0°
   - Load (50Ω): |S11| ≈ −40 dB or lower
4. Record calibration state in measurement log
5. **Do not move cables** between calibration and measurement

---

## Prototype Preparation

Before any electrical measurement:

1. Verify DC resistance of each winding with multimeter
   - Record value — establishes wire integrity
   - Compare against calculated value for wire gauge and length
2. Verify no inter-winding shorts (resistance between winding pairs should be open)
3. Verify no winding-to-former shorts (if using ferrite core)
4. Photograph prototype from four standardized angles:
   - Top view
   - Side view (0°)
   - Side view (90°)
   - Isometric
5. Record ambient temperature and humidity in measurement log

---

## Measurement Set A — Impedance Sweep (Primary)

This is the core dataset. Perform on every prototype.

### Setup

- Connect one winding terminal to VNA port 1 (S11 reflection)
- Leave all other windings open-circuit (floating, not grounded)
- Frequency range: 100 kHz to 30 MHz
  (adjust if self-resonant frequency falls outside this range)
- Sweep points: minimum 401, recommend 1001
- Averaging: 4× minimum
- IF bandwidth: 100 Hz or lower for clean trace

### Measurements to Record

| Parameter | Unit | Notes |
|---|---|---|
| \|Z\| vs. frequency | Ω | Impedance magnitude |
| Phase vs. frequency | degrees | |
| Rs vs. frequency | Ω | Series resistance component |
| Xs vs. frequency | Ω | Series reactance component |
| S11 magnitude | dB | Reflection coefficient |
| S11 phase | degrees | |

### Derived Parameters

Calculate and record:

- **Self-resonant frequency (SRF)** — frequency of first impedance peak
- **Second and third resonances** — if present within sweep range
- **Q factor at SRF**: Q = f_SRF / BW_−3dB
  where BW_−3dB is the −3 dB bandwidth around the resonance peak
- **Low-frequency inductance** — measured at 100 kHz (below SRF)
- **Distributed capacitance** — estimated from SRF and L:
  C_dist = 1 / ((2π · f_SRF)² · L)

### Perform For Each Winding Separately

Repeat Measurement Set A for:
- [ ] Primary winding alone (others floating)
- [ ] Counter winding alone (others floating)
- [ ] Harmonic winding alone (others floating)

---

## Measurement Set B — Coupling Coefficient

Measures inductive coupling between winding pairs.

### Setup

- Connect primary to VNA port 1
- Connect secondary (counter or harmonic) to VNA port 2
- All unused windings floating
- Two-port S-parameter measurement (S11, S21, S12, S22)
- Frequency range: 100 kHz to 10 MHz

### Derived Parameters

- **Mutual inductance M** — from S21 at low frequency
- **Coupling coefficient k** = M / √(L1 · L2)
- **Coupling frequency response** — |S21| vs. frequency

### Perform For Each Pair

- [ ] Primary → Counter
- [ ] Primary → Harmonic
- [ ] Counter → Harmonic

---

## Measurement Set C — Harmonic Spectrum Under Drive

Measures harmonic content when the device is actively driven.

### Setup

- Drive primary winding with function generator
- Drive frequency: start at 1 kHz, sweep to 100 kHz
- Drive amplitude: 1 Vpp (low level — avoid core saturation)
- Monitor output across secondary winding with oscilloscope
- Record FFT spectrum from oscilloscope

### Measurements to Record

- Fundamental amplitude at output
- 2nd, 3rd, 5th, 7th harmonic amplitudes
- Total harmonic distortion (THD) if measurable
- Resonance response under drive vs. impedance sweep results

---

## Measurement Set D — Thermal Behavior

Compares thermal loss between control and quasi-periodic prototypes.

### Setup

- Drive at identical power levels
- Allow 10 minutes for thermal stabilization
- Measure surface temperature with IR thermometer or thermal camera
- Record at 4 standardized measurement points around toroid

### Note

Thermal differences, if present, indicate loss mechanism differences —
not efficiency gains. Any thermal data is loss characterization only.

---

## Comparative Protocol

The experiment has no value without a valid control.

### Control Structure (Prototype V0)

- Conventional periodic winding
- Identical toroid dimensions: R = 89 mm, r = 55 mm
- Identical wire gauge and total wire length
- Identical turn count
- Evenly spaced turns (360° / N spacing)

### Comparison Rules

1. Both prototypes measured on the same instrument
2. Both measurements taken within the same session where possible
3. Same calibration used for both
4. Same ambient conditions (temperature, humidity)
5. Both measurements repeated minimum 3 times; report mean ± std dev

### What Constitutes a Meaningful Difference

A difference is considered potentially significant if:

- It exceeds 3× the measurement uncertainty
- It is reproducible across ≥ 3 independent measurement runs
- It is present on both impedance sweep AND another measurement set

A single anomalous reading is not a result. Reproducibility is everything.

---

## Data Storage

All measurement data stored in `/data/` following naming convention:

```
data/
  prototype_v0/
    YYYY-MM-DD_run01_impedance_primary.csv
    YYYY-MM-DD_run01_coupling_p-c.csv
    YYYY-MM-DD_run01_notes.md
  prototype_v1/
    YYYY-MM-DD_run01_impedance_primary.csv
    ...
```

Raw VNA data exported as CSV or S2P (Touchstone format).
Never modify raw data files — create processed copies for analysis.

---

## Instrumentation Notes

### NanoVNA / LiteVNA Specific

- Use NanoVNA-saver software for PC-based sweep capture
- Export as S1P (one-port) or S2P (two-port) Touchstone format
- Perform calibration with the included SOLT cal kit
- Minimum 201 points; 1001 points recommended for SRF characterization

### LCR Meter Specific

- Measure inductance at 1 kHz, 10 kHz, and 100 kHz
- Record all three — frequency dependence reveals distributed effects
- Use 4-wire (Kelvin) connection if available to exclude lead resistance

---

## Safety Notes

- All measurements are low-voltage, low-power — no significant hazard
- Avoid driving windings at high power near SRF without current limiting
- Ferrite cores can chip — handle carefully, wear eye protection when cutting

---

*"We don't know what we'll find. That's the point."*

*See also: [hypothesis.md](hypothesis.md) · [measurement_log_template.md](measurement_log_template.md) · [geometry.md](geometry.md)*

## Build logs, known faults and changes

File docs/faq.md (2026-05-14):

# FAQ — Frequently Asked Questions

---

## What is this project?

An open experimental investigation into whether quasi-periodic toroidal
winding geometries exhibit measurable electromagnetic behaviors different
from conventional periodic toroidal windings.

We are building physical prototypes, measuring them with real instruments,
and documenting everything openly so others can replicate or challenge the results.

---

## Is this a free energy device?

**No.**

This project makes no claim of overunity performance, excess energy generation,
or any output exceeding input. The laws of thermodynamics are not under
investigation here.

---

## Is this perpetual motion?

**No.**

---

## Does this extract energy from the vacuum / zero point field?

**No claim of this kind is made.**

The project investigates whether winding geometry affects measurable
electromagnetic parameters — inductance, resonance, coupling, bandwidth.
That is the entirety of what is being tested.

---

## Is this Tesla free energy technology?

**Inspired by, not claiming.**

Nikola Tesla's emphasis on resonance, harmonic systems, and toroidal geometry
is an acknowledged conceptual inspiration for the geometric choices made here.

This project does not claim to replicate Tesla's suppressed inventions,
reproduce Wardenclyffe Tower behavior, or demonstrate any of Tesla's
alleged but unverified discoveries.

---

## Are you claiming anomalous physics?

**No.**

The hypothesis is straightforward: winding geometry affects electromagnetic
behavior. This is already well-established in antenna theory, metamaterial
research, and resonator design. We are investigating whether it is also
meaningful in toroidal inductor topology.

If it is: interesting and potentially useful.
If it is not: also interesting, and the data will say so clearly.

---

## What does the golden ratio / Fibonacci / phi have to do with this?

The golden angle (137.5°) derived from the golden ratio is used as the
angular spacing between winding turns. This is a geometric design choice
with a specific mathematical property: irrational angular spacing means
no two turns ever occupy the same angular position, regardless of turn count.

This property — known as maximal irrationality — is why phyllotaxis
(sunflower seeds, pinecone scales) uses the same angle for optimal packing.

Whether this property produces useful electromagnetic effects in a toroidal
inductor is the experimental question. We do not assume the answer.

---

## Why toroids specifically?

Toroidal inductors are a well-characterized baseline. Their electromagnetic
behavior is well-understood, making it easier to identify genuine deviations
from expected behavior. They are also self-shielding, compact, and
widely used — making any findings potentially applicable.

---

## What measurement instruments are you using?

Primary measurement instrument: NanoVNA or equivalent vector network analyzer.
Supplementary: LCR meter, multimeter, oscilloscope.

All instruments are consumer-grade but calibrated and adequate for
the measurements being performed (impedance sweeps to 30 MHz,
inductance at audio frequencies, Q factor characterization).

---

## Can I replicate this?

Yes. That is the point.

Everything needed to replicate this project is in this repository:
- CAD files for the toroid former
- Build guides with complete materials lists
- Measurement protocols
- Blank measurement log templates
- Data analysis scripts

If you build one and measure it, please submit your data as a pull request
or open an issue. Independent replication is the most valuable contribution
you can make.

---

## Where is the data?

In the `/data/` directory. All raw measurement files (VNA Touchstone format,
CSV) are posted as they are collected. Nothing is withheld.

If the data shows nothing interesting, it will be posted anyway.
Null results are results.

---

## Who is doing this research?

R. Wierzbicki, independent researcher, USA, 2026.
Small shop. Shoestring budget. Genuine curiosity.

---

## What do you expect to find?

Honestly: we don't know. That's why we're measuring.

The geometric reasoning suggests there might be differences in resonance
distribution and distributed capacitance. Adjacent research in aperiodic
EM structures (fractal antennas, quasi-crystal resonators) suggests
non-periodic geometry can matter. Whether it matters here, and how much,
will be determined by measurement.

---

## What if you find nothing?

Then the data clearly shows that conventional and quasi-periodic toroidal
windings behave identically within measurement precision.

That is a valid result. It would suggest that winding periodicity is not
a meaningful variable for this geometry and scale.

The data goes up either way.

---

*"Extraordinary claims require extraordinary evidence — we have none yet."*

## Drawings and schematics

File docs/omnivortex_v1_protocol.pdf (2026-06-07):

## Omnivortex V1 — Phase 1 Measurement Protocol

R=89mm r=55mm · 123 turns · 22 AWG · 3.0Ω DC | github.com/Te55er4ct/phi-harmonic-toroidal-field

Pre-measurement environment check
Laptop on battery · WiFi off · Wooden sawhorse bench · Confirm DC resistance = 3.0Ω before any RF measurement
Step 1 — LCR meter: Inductance and Q factor Proster LCR
Step 2 — NanoVNA: self-resonant frequency (SRF) NanoVNA-H · Port CH0

2a Calibrate NanoVNA
Perform OSL (Open / Short / Load)
Use same SMA pigtails as measurement Span: 100 kHz → 30 MHz
Port 1 (CH0) only for SRF scan

2b Locate SRF peak
Plot |Z| or S11 on screen
SRF = frequency at |Z| maximum Coil acts capacitive above SRF Log exact frequency in MHz

SRF cross-check formula
SRF = 1 / (2 x pi x sqrt(L x C_self)) — use measured L to back-calculate C_self after SRF is known
Step 3 — NanoVNA: impedance sweep 100 kHz NanoVNA-H | → 30 MHz

Post-measurement calculations
Wheeler toroid: L = u0 x N^2 x A / (2 x pi x R) where A = pi x r^2
A = pi x (0.055)^2 = 9.503e-3 m^2 R = 0.089 m N = 123
L_predicted ~ u0 x 15129 x 9.503e-3 / (2 x pi x 0.089) ~ 3.23 mH (expect 5-15% lower measured) C_self (from SRF): C = 1 / (4 x pi^2 x f_SRF^2 x L) Q = omega x L / R_ESR

Wierzbicki Phenomenon Omnivortex Device Project · V1 Phase 1 · github.com/Te55er4ct/phi-harmonic-toroidal-field

## Omnivortex V1 — Measurement Log Sheet

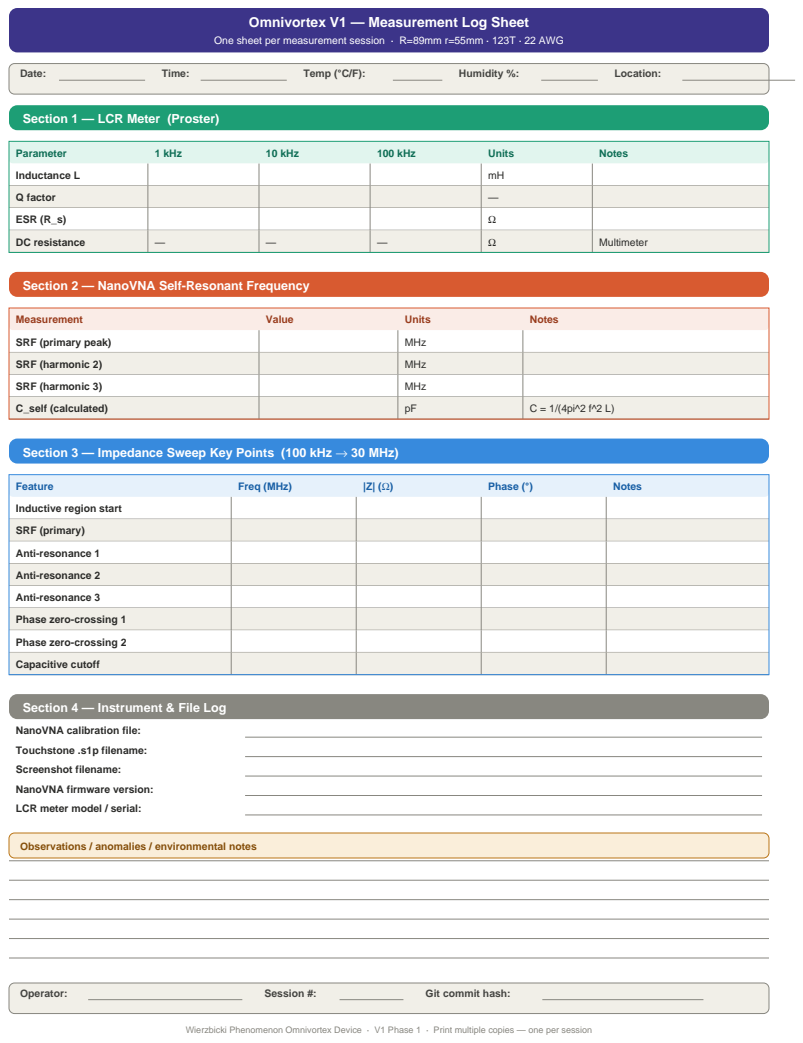
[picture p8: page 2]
Date:; Time:; Temp (°C/F):; Humidity %:; Location:; Parameter; 1 kHz; 10 kHz; 100 kHz; Units; Notes; Inductance L; Q factor; ESR (R_s); DC resistance; Multimeter; Measurement; Value; SRF (primary peak); MHz; SRF (harmonic 2); SRF (harmonic 3); C_self (calculated); Feature; Freq (MHz); Phase (°); Operator:; Session #:; Git commit hash:

One sheet per measurement session · R=89mm r=55mm · 123T · 22 AWG

Section 1 — LCR Meter (Proster)

Section 2 — NanoVNA Self-Resonant Frequency

Section 3 — Impedance Sweep Key Points (100 kHz → 30 MHz)

Inductive region start
SRF (primary)
Anti-resonance 1
Anti-resonance 2
Anti-resonance 3
Phase zero-crossing 1
Phase zero-crossing 2
Capacitive cutoff

Section 4 — Instrument & File Log

NanoVNA calibration file:
Touchstone .s1p filename:
Screenshot filename:
NanoVNA firmware version:
LCR meter model / serial:

Observations / anomalies / environmental notes

Wierzbicki Phenomenon Omnivortex Device · V1 Phase 1 · Print multiple copies — one per session

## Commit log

2026-06-07 Add V1 session 1 protocol, model, and SRF measurement screenshot
    Includes the 1-1.2MHz NanoVNA sweep showing series L readings (1.65-1.75mH) used in the Wheeler formula comparison.
    [master_blank_torus_V1_baseline_section3.1.3mf]
2026-06-07 Add build/measurement photos for V1 session 1
    Print, cure, OpenSCAD render, winding/terminals, inductance and resistance meter readings.
2026-06-22 Add GitHub Pages site — phi-harmonic toroidal field V1
